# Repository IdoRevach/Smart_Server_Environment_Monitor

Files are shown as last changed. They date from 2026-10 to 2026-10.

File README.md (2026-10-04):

# Smart Server Environment Monitor

I leave a local server running my backend projects 24/7, and I want a physical dashboard to monitor its physical environment. 

I'll use a Raspberry Pi 4, a DHT22 sensor, and some LEDs inside a custom case. The Pi will run a web server so I can check the stats, and the LEDs will alert me if the area around the hardware gets too warm.

## System Architecture

The system reads temperature and humidity data from the DHT22 sensor, processes it on the Raspberry Pi 4, and triggers the warning LEDs if thresholds are exceeded. Below is the initial design concept:

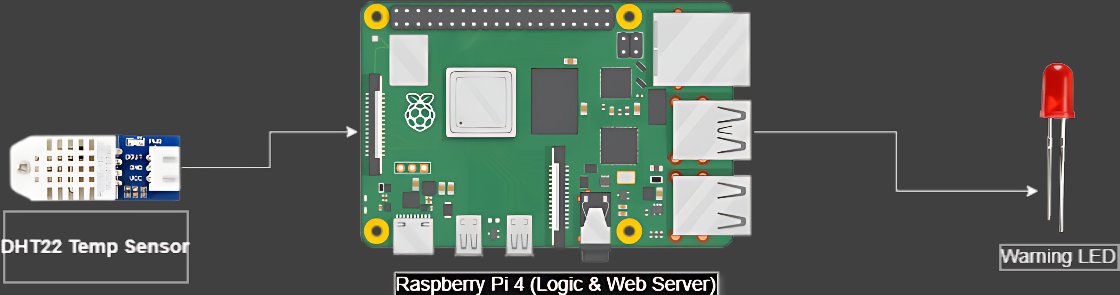
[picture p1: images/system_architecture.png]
System Architecture


## Why a Raspberry Pi 4?

I know an ESP32 or Arduino could just read a sensor and turn on a light. The problem is that reading the live temperature is not enough here. I want to save the data history to see if the server area is getting hotter over time.

That is why I am going with the Pi 4. It works like an actual server. I can run Node.js and a SQLite database right on the board to keep months of records. Small microcontrollers do not handle databases and web dashboards very well. Also, having a real Linux system means I can easily add Discord or WhatsApp alerts later without dealing with annoying C++ network code.

## Hardware List

The core components for this build are:

* Raspberry Pi 4 Model B
* DHT22 Temperature and Humidity Sensor
* Red Warning LED
* Basic wiring parts (jumper wires and a resistor)

### Wiring Schematic

The schematic below outlines the GPIO connections for the components. The DHT22 requires 3.3V power, and the status LED is connected with a 330Ω resistor to prevent overdrawing current from the Pi.

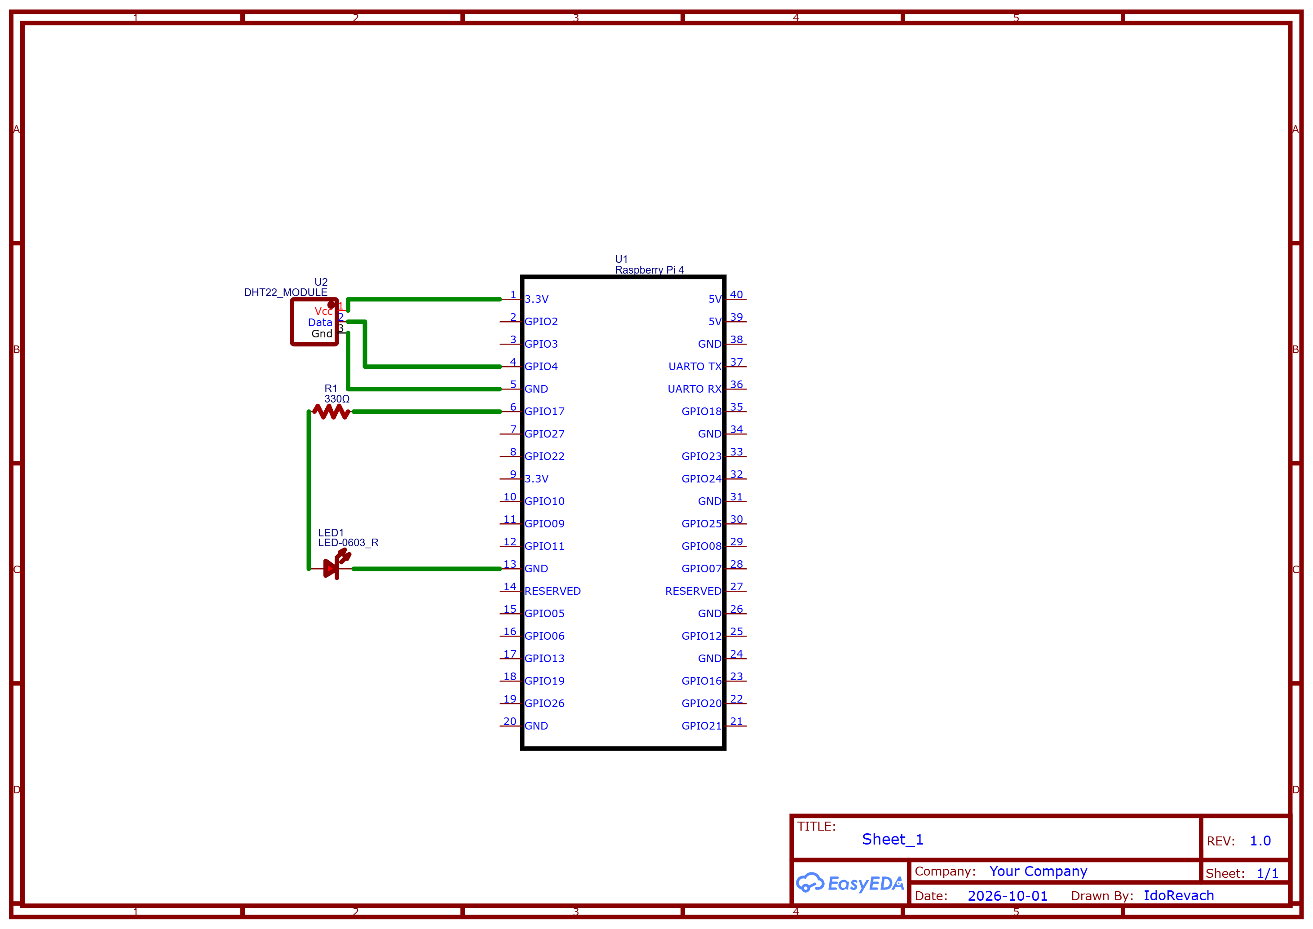
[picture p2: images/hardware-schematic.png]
hardware-schematic


### Software Stack

The backend is written in Node.js, running as a background service on the Pi. I wanted a lightweight stack that can poll the sensor, log the data, and serve a simple dashboard without eating up system resources.

*   **Node.js Server:** Handles the main polling loop for the DHT22 and runs the API endpoints.
*   **SQLite:** Used for local data logging. It's perfectly suited for this because it stores everything in a single local file, avoiding the overhead of a full database server while still letting me query historical temperature trends.
*   **GPIO Control:** The backend parses the sensor data and pulls GPIO17 HIGH to trigger the warning LED if the temperature crosses a defined threshold.
*   **Frontend Dashboard:** A basic HTML/JS page that fetches the latest stats from the Node API to display current temperature, humidity, and the LED warning status.

## Enclosure & 3D Design

I'm currently applying for a hardware grant through Hack Club's Half Life program, so I don't have the Raspberry Pi 4 or the sensors yet. To make sure the project is ready when the parts arrive, I designed a custom enclosure in Onshape.

Leaving a bare board and breadboard sitting on my server isn't ideal. Also, since Pi 4s are known to run hot, I had to make sure the board's heat wouldn't affect the DHT22 readings. The case design includes ventilation slots to isolate the sensor and allow for proper airflow.

The 3D renders and STL files are available below:

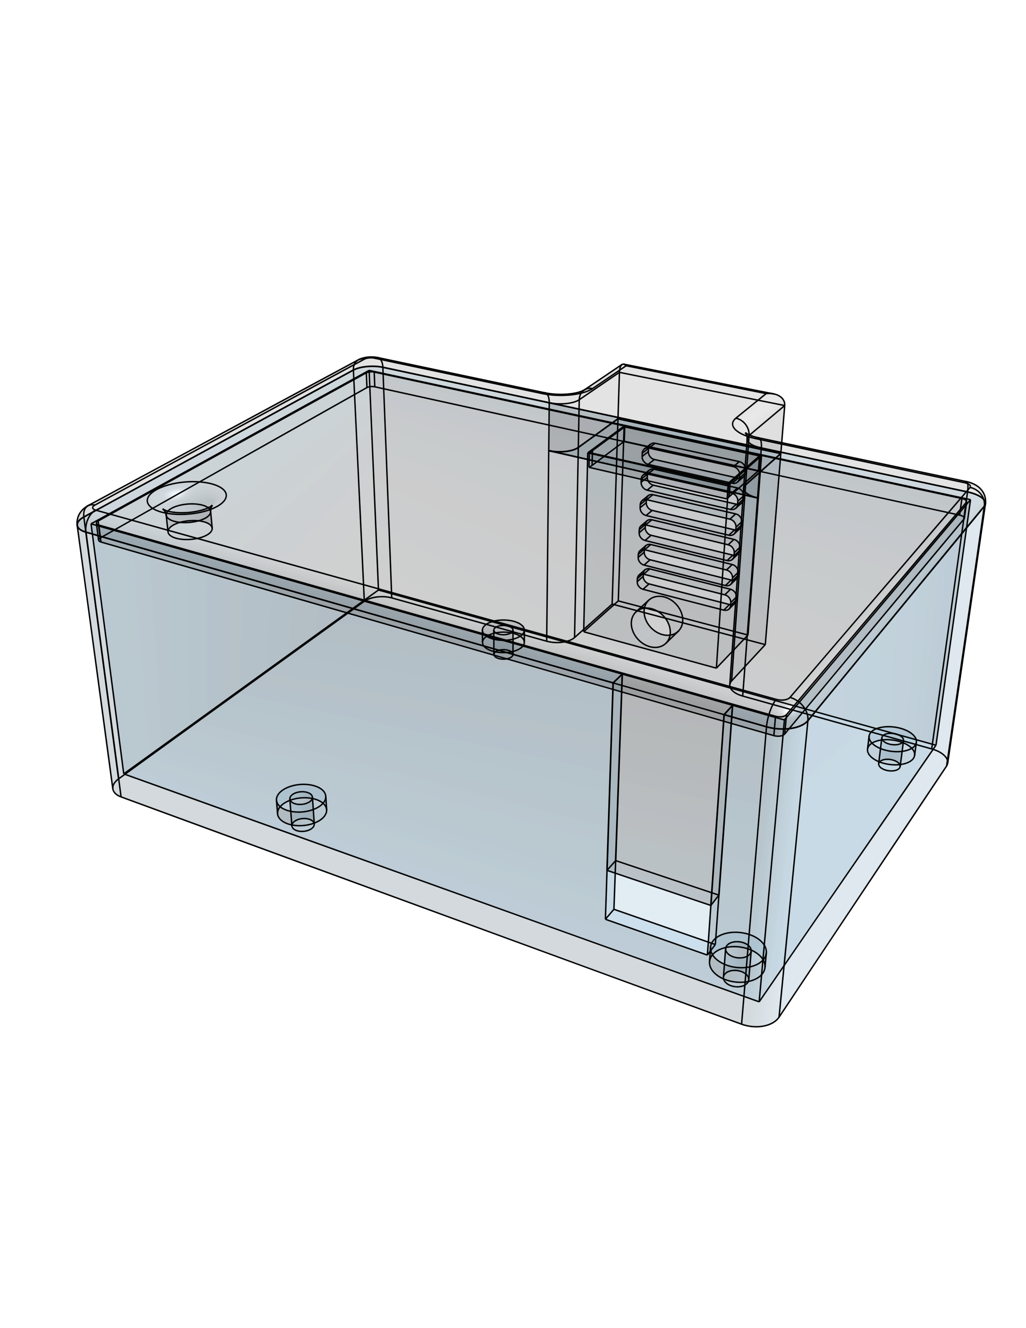
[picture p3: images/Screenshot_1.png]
Enclosure Internals

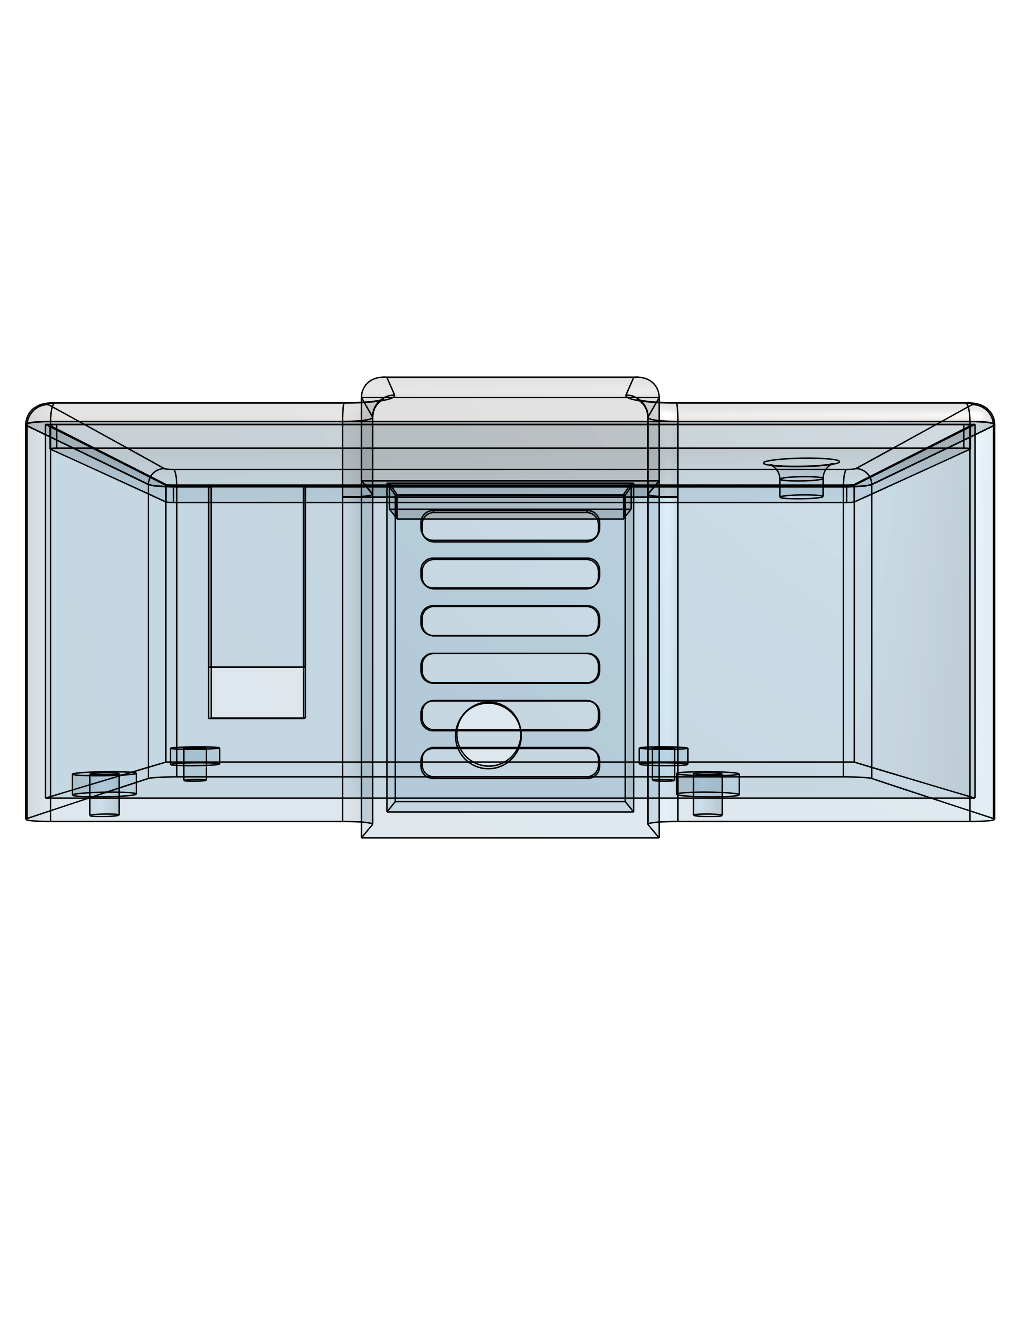
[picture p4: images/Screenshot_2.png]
Enclosure Top View

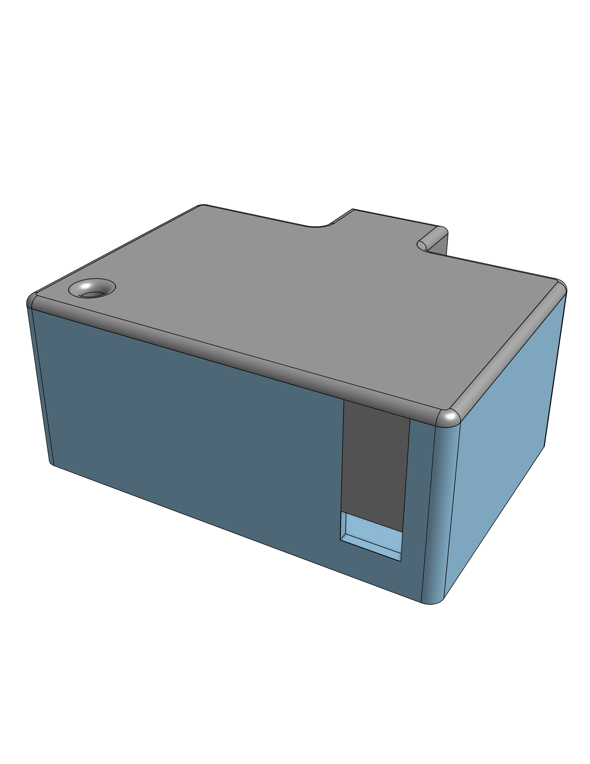
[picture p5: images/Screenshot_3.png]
Enclosure Side View

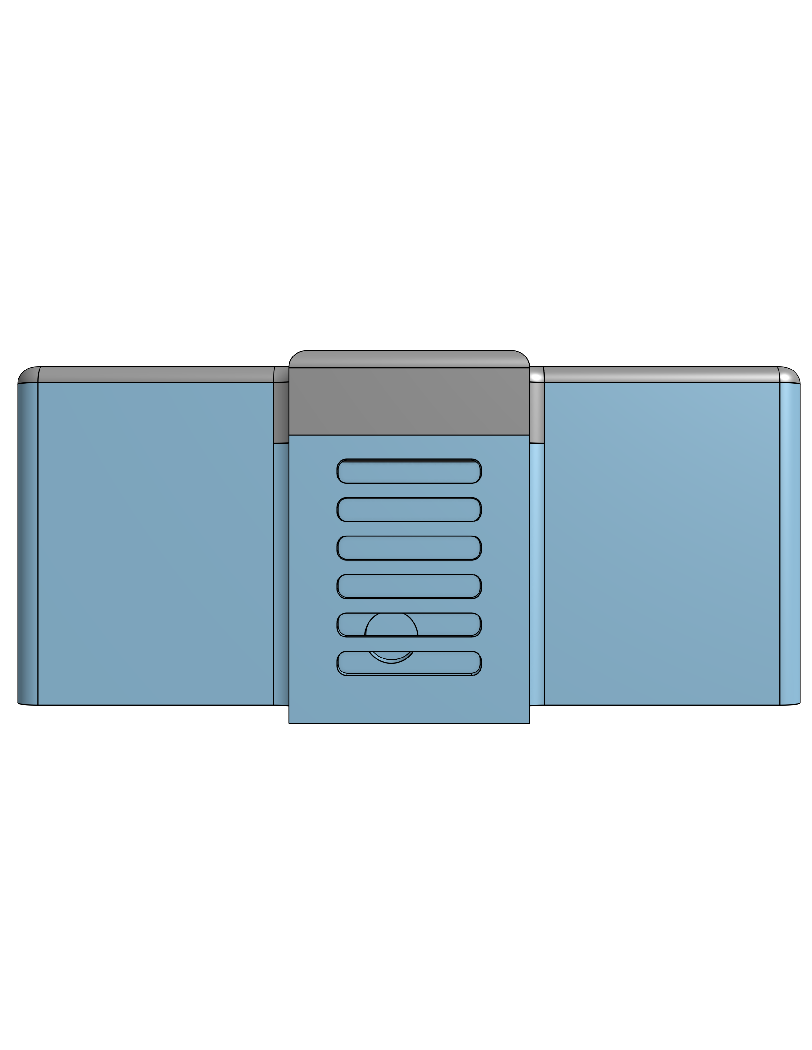
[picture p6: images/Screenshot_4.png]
Enclosure Front View


* [Base STL Model](stl/SentinelNode_RPi4_Base_v1.stl)
* [Lid STL Model](stl/SentinelNode_RPi4_Lid_v1.stl)

### Reality Check and Design Pivot
When I started putting together the final parts list I hit a wall with the Tier 2 funding limit. A Raspberry Pi 4 costs way more than the 65 dollars allowed. I looked into moving up to Tier 3, but that requires adding a motorized component to the build. Adding a fan or a servo just to inflate the budget felt like over engineering a project that should remain simple and reliable.

This forced me to look back at my original reason for using a Pi 4. I wanted to avoid writing annoying network code in C++ and I wanted a real database to keep history. Then I realized that the physical monitor is literally sitting right next to my 24/7 backend server. There is no reason the monitor itself needs to host the database.

I am swapping the Pi 4 for a cheap ESP32 C6 development board. The ESP32 will act as a dumb sensor node. All it has to do is read the DHT22 and send a basic HTTP POST request over the local Wi-Fi to my main server. My actual server will run the Node.js API, write the history to SQLite, and host the web dashboard. This keeps the project well within the Tier 2 budget and honestly makes the whole architecture much smarter by offloading the heavy work to the machine that is actually built for it.

### V2 Architecture: The Distributed Approach

With the pivot to the ESP32-C6, the system architecture is now distributed. The ESP32 acts purely as an edge sensor node, while my existing 24/7 server handles the backend logic, database, and dashboard.

**1. The Edge Node (ESP32-C6):**
The microcontroller's only job is to poll the DHT22 sensor for temperature and humidity data and send it as a JSON payload via HTTP POST requests over the local Wi-Fi. It also controls the red warning LED, toggling it based on predefined temperature thresholds to provide immediate physical feedback.

**2. The Backend (Existing Local Server):**
Instead of running on the monitor itself, the Node.js API and SQLite database now live on my main server. The backend receives the incoming POST requests, securely logs the timeseries data into the SQLite database, and serves the frontend web dashboard. 

Here is the updated system architecture:

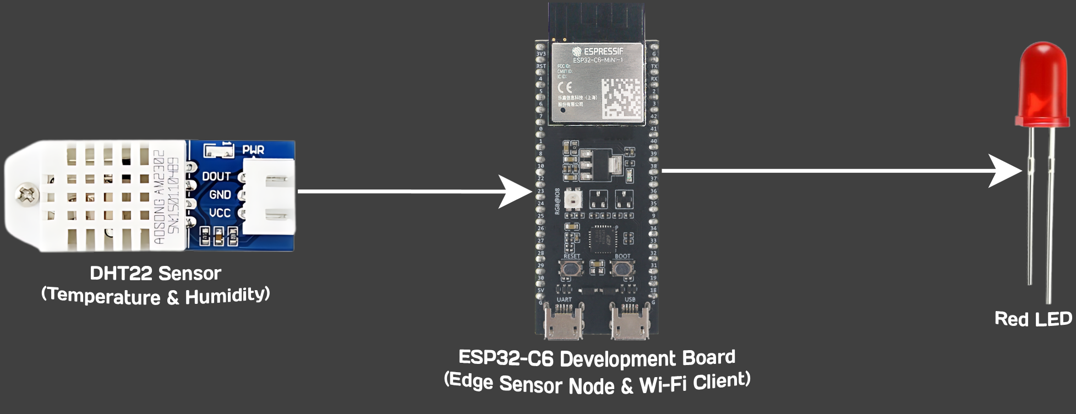
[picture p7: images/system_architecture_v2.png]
System Architecture V2


### Updated V2 Hardware Design

Below is the updated engineering schematic for the new ESP32-C6 electrical setup:

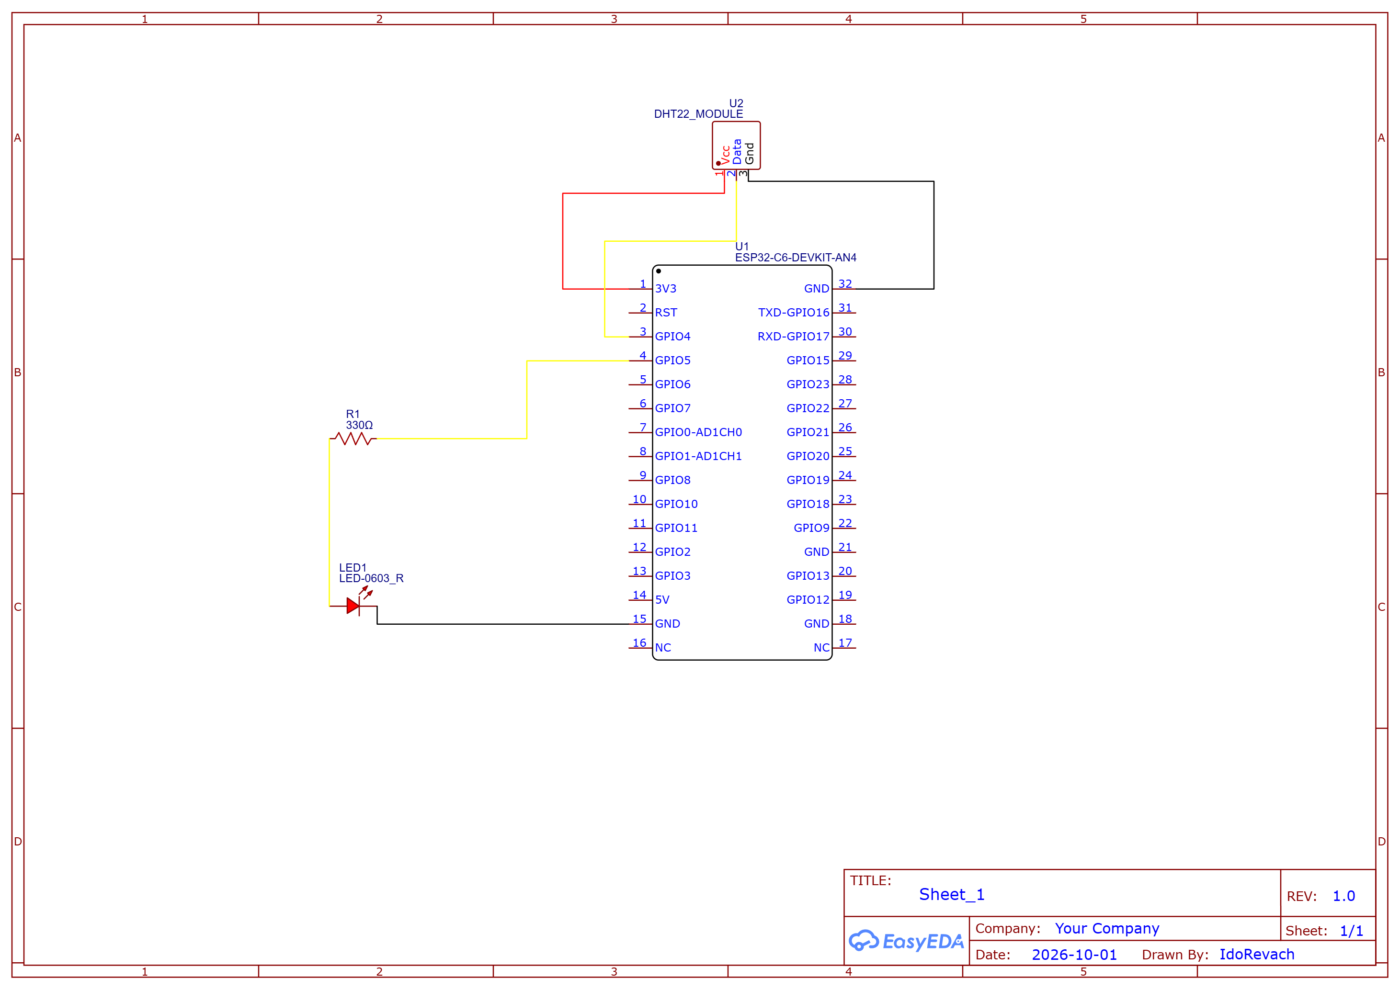
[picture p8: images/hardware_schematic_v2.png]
Electrical Schematic V2


## 3D Enclosure
I had to update the Onshape model to fit the ESP32 footprint instead of the Pi. The case separates the sensor from the board's heat.

The 3D renders and STL files are available below:

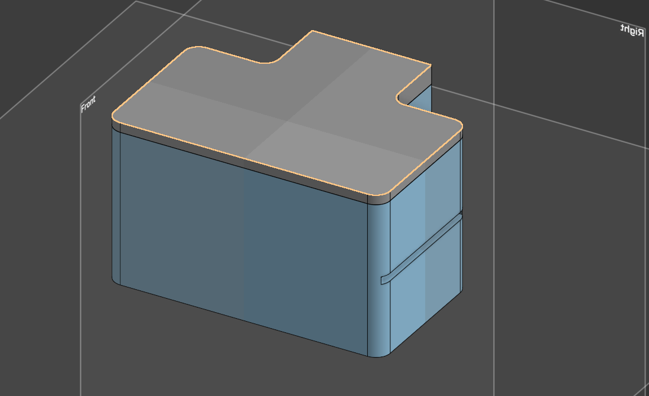
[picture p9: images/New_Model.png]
Case Front

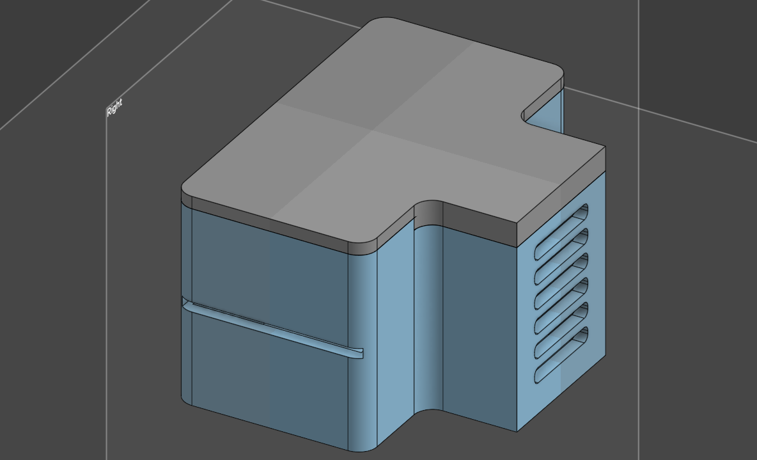
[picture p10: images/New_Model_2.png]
Case Side

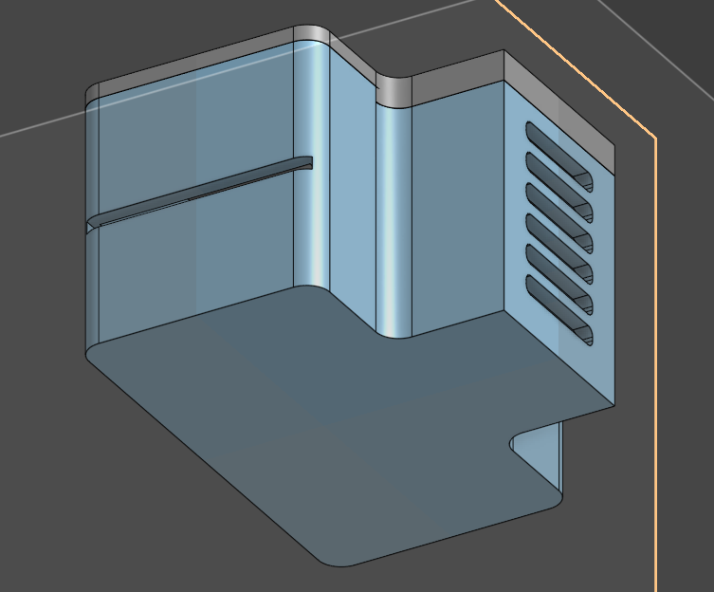
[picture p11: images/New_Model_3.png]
Case Internals


* [Base STL Model](stl/SentinelNode_ESP32_Base_v2.stl)
* [Lid STL Model](stl/SentinelNode_ESP32_Lid_v2.stl)

## Code & Setup
I uploaded everything straight to the root directory for now. (Note: I accidentally named them `main.py.py` and `server.js.js` on upload, just rename them back to normal when you clone).

* **ESP32:** Flash it with MicroPython, update the Wi-Fi details, and run `main.py`.
* **Backend:** Run `npm install express better-sqlite3`. 
* **Dashboard:** Make a folder called `public` next to the server script and put `index.html` inside it. 
* Run `node server.js` and hit port 3000 in your browser.

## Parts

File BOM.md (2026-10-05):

# Smart Server Environment Monitor — bill of materials

<!-- Generated by Half Life from project cmuoqo1p400re01s1fbd7emb1. Edits here are overwritten on the next sync. -->
<!-- Generated: 2026-10-05T03:29:06.988Z -->

> [!NOTE]
> This parts list is mirrored from [Half Life](https://halflife.hackclub.com). Editing it here will not change the platform's copy, and the next sync overwrites this file.

| Week | Tier | Parts funding |
| --- | --- | --- |
| Warm-up | Tier 2 | $65.00 |

| Part | What it's for | Qty | Unit | Total | Vendor |
| --- | --- | --- | --- | --- | --- |
| [ESP32-C6-N16 development board (pin soldered)](https://piitel.co.il/shop/esp32-c6-n16-development-board-pin-soldered/) | Main controller (reads sensor and handles Wi-Fi POST requests) | 1 | $16.18 | $16.18 | [Piltel](https://piitel.co.il/shop/esp32-c6-n16-development-board-pin-soldered/) |
| [DHT22/AM2302 Temperature & Humidity Sensor](https://www.4project.co.il/product/grove-temperature-humidity-sensor-pro-am2302-dht22) | Reads the physical environment data | 1 | $15.92 | $15.92 | [4Project](https://www.4project.co.il/product/grove-temperature-humidity-sensor-pro-am2302-dht22) |
| [Red LED 10mm](https://www.4project.co.il/product/basic-led-10mm-red) | Warning indicator | 1 | $0.61 | $0.61 | [4Project](https://www.4project.co.il/product/basic-led-10mm-red) |
| [330 Ohm Resistors 1/4W (Pack of 10)](https://www.4project.co.il/product/resistor-330-kilo-ohm-0.25w-pth) | Current limiting to protect the LED | 1 | $0.97 | $0.97 | [4Project](https://www.4project.co.il/product/resistor-330-kilo-ohm-0.25w-pth) |
| [Female to Female Jumper Wires 20cm (40 pcs)](https://www.4project.co.il/product/dupont-cable-40p-20cm-female-female) | Wiring the DHT22 and LED to the ESP32 pins | 1 | $1.91 | $1.91 | [4Project](https://www.4project.co.il/product/dupont-cable-40p-20cm-female-female) |
| **Parts subtotal** | — | — | — | **$35.59** | — |
| **Tax & shipping** | — | — | — | **$14.40** | — |
| **Total** | — | — | — | **$49.99** | — |

$15.01 left of the tier's funding.

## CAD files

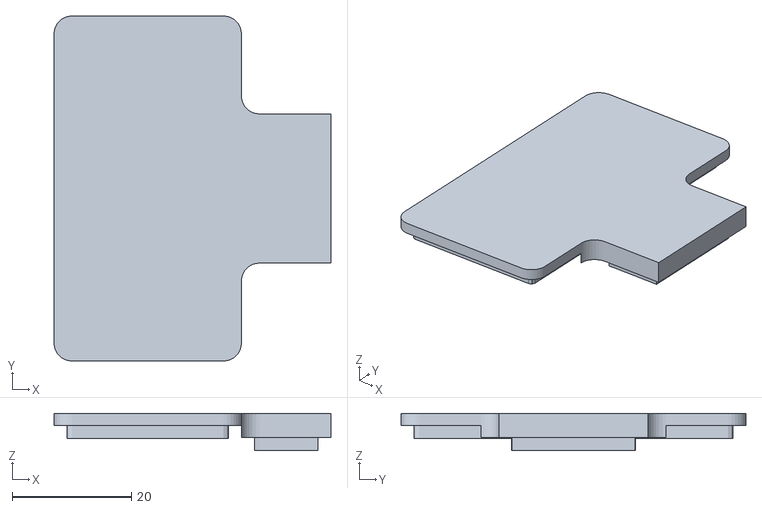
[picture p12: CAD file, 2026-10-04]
stl/SentinelNode_ESP32_Lid_v2.stl
46.4 x 57.8 x 6.20

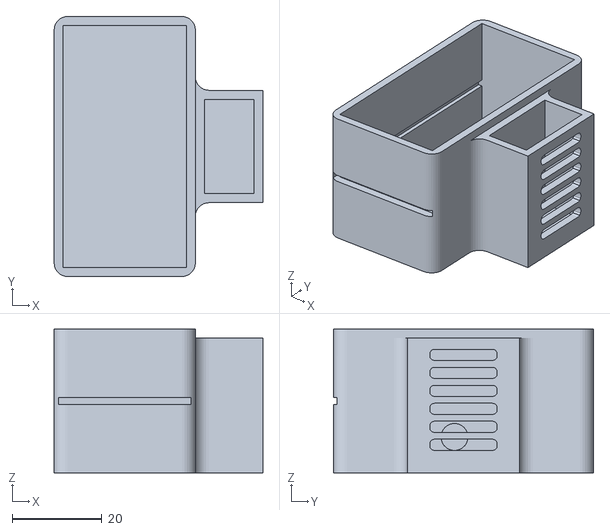
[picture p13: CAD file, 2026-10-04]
stl/SentinelNode_ESP32_Base_v2.stl
46.4 x 57.8 x 32.0

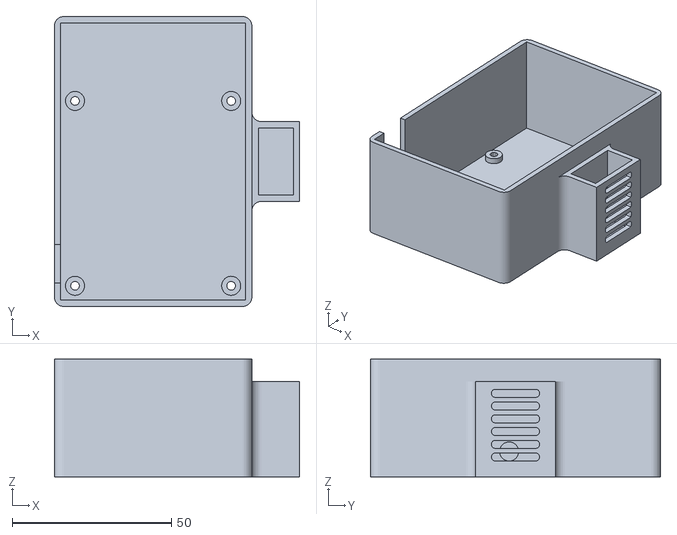
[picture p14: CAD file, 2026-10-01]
stl/SentinelNode_RPi4_Base_v1.stl
77.0 x 91.0 x 37.0

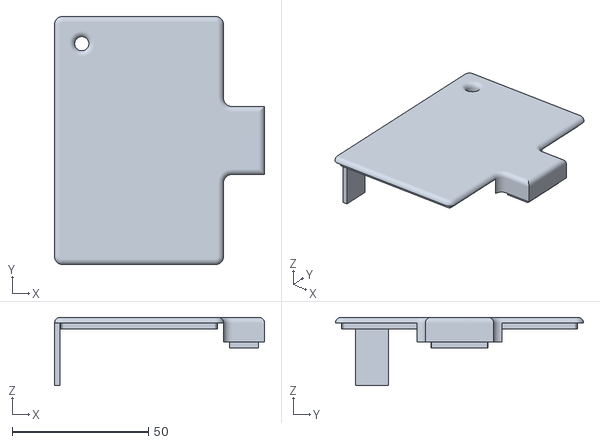
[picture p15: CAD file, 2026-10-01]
stl/SentinelNode_RPi4_Lid_v1.stl
77.0 x 91.0 x 25.0

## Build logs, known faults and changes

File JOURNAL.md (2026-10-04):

# Smart Server Environment Monitor — devlog

<!-- Generated by Half Life from project cmuoqo1p400re01s1fbd7emb1. Edits here are overwritten on the next sync. -->
<!-- Generated: 2026-10-04T20:59:15.338Z -->

> [!NOTE]
> This devlog is mirrored from [Half Life](https://halflife.hackclub.com). Editing it here will not change the platform's copy, and the next sync overwrites this file.

> I leave a local server running my backend projects 24/7, and I want a physical dashboard to monitor its physical environment. I'll use a Raspberry Pi 4, a DHT22 sensor, and some LEDs inside a custom case. The Pi will run a web server so I can check the stats, and the LEDs will alert me if the area around the hardware gets too warm.

| Week | Tier | Hours logged | Entries |
| --- | --- | --- | --- |
| Warm-up | Tier 2 | 17h | 4 |

## Contents

1. [2026-10-01 — Spent this session researching the components, planning the stack, and getting the 3D design done.](#2026-10-01-spent-this-session-researching-the-components-pla)
2. [2026-10-01 — Spent this session finalizing the Bill of Materials (BOM) and doing a reality check on local hardware prices. It turns out the Raspberry Pi 4 is way too expensive locally and blows right past the $65](#2026-10-01-spent-this-session-finalizing-the-bill-of-materia)
3. [2026-10-02 — Spent this session updating the docs and diagrams for the new V2 architecture. Since I swapped the Pi for an ESP32-C6, the old schematics were totally useless.](#2026-10-02-spent-this-session-updating-the-docs-and-diagrams)
4. [2026-10-04 — Spent this session doing some final research for the project pivot. I drew up the new hardware schematics and wrote all the code for both the server and the sensor node. To finish things off I updated](#2026-10-04-spent-this-session-doing-some-final-research-for-)

## Design

### 2026-10-01 — Spent this session researching the components, planning the stack, and getting the 3D design done.

**6.5h**

Spent this session researching the components, planning the stack, and getting the 3D design done.

I started with some research into the hardware requirements to pick the right parts for the job. Instead of a basic microcontroller, I went with a Raspberry Pi 4 so I can run Node.js









hardware-schematic

 and a local SQLite database to log temperature trends over time. I mapped out the wiring for the DHT22 sensor and warning LED (including the 330Ω resistor), planned the architecture, and wrote the documentation in the README.

After that, I modeled the custom enclosure in Onshape. Knowing the Pi 4 runs warm, I designed ventilation slots and isolated the DHT22 mount so the board heat will not mess with ambient readings. Finally, I exported the STLs, organized the repository into clean /images and /stl folders, and synced everything up.

system_architecture 1



### 2026-10-01 — Spent this session finalizing the Bill of Materials (BOM) and doing a reality check on local hardware prices. It turns out the Raspberry Pi 4 is way too expensive locally and blows right past the $65

**1.5h**

Spent this session finalizing the Bill of Materials (BOM) and doing a reality check on local hardware prices. It turns out the Raspberry Pi 4 is way too expensive locally and blows right past the $65 Tier 2 funding limit, even before calculating shipping and taxes.

I considered pushing the project to Tier 3, but that requires integrating a motorized component. Forcing a fan or a servo into the build just to get a bigger budget felt like bad engineering and unnecessary complexity for a simple environmental monitor.

Instead of over-engineering the hardware, I decided to pivot the architecture. Since this physical monitor will sit right next to my main 24/7 backend server anyway, I don't need a full Linux board to run a local SQLite database. I'm swapping the Pi 4 out for an ESP32-C6 development board. The ESP32 will act purely as a sensor node, reading the DHT22 and sending HTTP POST requests over Wi-Fi to my existing server, which will handle the Node.js API and data logging. This keeps the project under budget and makes the overall system architecture much cleaner.

צילום מסך 2026-10-01 215020

parts_02

parts_01

parts_03

### 2026-10-02 — Spent this session updating the docs and diagrams for the new V2 architecture. Since I swapped the Pi for an ESP32-C6, the old schematics were totally useless.

**2h**

Spent this session updating the docs and diagrams for the new V2 architecture. Since I swapped the Pi for an ESP32-C6, the old schematics were totally useless.

I hopped into EasyEDA and drew up a new electrical schematic. Kept it simple: the DHT22 data line goes to GPIO4, and the warning LED (with a 330Ω resistor) is on GPIO5.

After that, I made a new visual system diagram in draw.io to show exactly how the ESP32 connects to my existing local server via HTTP POST. I updated the README on GitHub with the new diagrams and wrote a quick breakdown of the distributed setup (ESP32 reads the environment, my main server handles the Node.js API and SQLite database).

The hardware logic is fully documented now. Next step is jumping into Onshape to shrink the 3D enclosure so the ESP32 actually fits.

system_architecture_v2

hardware_schematic_v2

### 2026-10-04 — Spent this session doing some final research for the project pivot. I drew up the new hardware schematics and wrote all the code for both the server and the sensor node. To finish things off I updated

**7h**

Spent this session doing some final research for the project pivot. I drew up the new hardware schematics and wrote all the code for both the server and the sensor node. To finish things off I updated the README file with the new design details and the updated images. Everything is finally ready.

New_Model_3

New_Model

New_Model_2

code_03

code_02

code_01

code_04

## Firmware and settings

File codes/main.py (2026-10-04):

import network
import time
import machine
import dht
import urequests

ssid = "MyWiFiNetwork"
password = "MyPassword123"
server_url = "http://192.168.1.14:3000/api/telemetry"
api_key = "halflife-esp32-key"

print("Booting up ESP32 Monitor...")

# Hardware setup based on the v2 schematic
sensor = dht.DHT22(machine.Pin(4))
led = machine.Pin(5, machine.Pin.OUT)
led.value(0) # start with LED off

wlan = network.WLAN(network.STA_IF)
wlan.active(True)
wlan.connect(ssid, password)

print("Connecting to WiFi", end="")
while not wlan.isconnected():
    print(".", end="")
    time.sleep(0.5)
print("\nConnected! IP Address:", wlan.ifconfig()[0])

while True:
    try:
        # make sure we are still online
        if not wlan.isconnected():
            print("WiFi disconnected! Reconnecting...")
            wlan.connect(ssid, password)
            while not wlan.isconnected():
                time.sleep(1)
            print("Reconnected.")

        print("Reading sensor...")
        sensor.measure()
        t = sensor.temperature()
        h = sensor.humidity()
        
        print(f"Temp: {t}C, Humidity: {h}%")
        
        # trigger local warning if it gets too hot (28C is the threshold for now)
        if t > 28.0:
            print("WARNING: Temp over 28! LED ON")
            led.value(1)
            alert = 1
        else:
            led.value(0)
            alert = 0
            
        payload = {
            "temperature": t,
            "humidity": h,
            "alert_active": alert
        }
        
        headers = {"Content-Type": "application/json", "x-api-key": api_key}
        
        print(f"Sending POST to {server_url}...")
        res = urequests.post(server_url, json=payload, headers=headers)
        print("Server responded with status:", res.status_code)
        
        # MUST close this or the ESP32 will run out of memory after a few hours
        res.close()
        
    except Exception as e:
        # just log it and keep going, don't crash the loop
        print("An error occurred in the loop:", e)
        
    print("Sleeping for 15 seconds...\n---")
    time.sleep(15)

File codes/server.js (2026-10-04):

const express = require('express');
const Database = require('better-sqlite3');
const path = require('path');

const app = express();
const PORT = process.env.PORT || 3000;
const API_KEY = process.env.API_KEY || 'halflife-esp32-key';

const db = new Database('monitor.db');
db.pragma('journal_mode = WAL');

db.exec(`
  CREATE TABLE IF NOT EXISTS telemetry (
    id INTEGER PRIMARY KEY AUTOINCREMENT,
    timestamp DATETIME DEFAULT CURRENT_TIMESTAMP,
    temperature REAL NOT NULL,
    humidity REAL NOT NULL,
    alert_active INTEGER NOT NULL
  )
`);

// Prepare statements once for better performance
const insertTelemetry = db.prepare('INSERT INTO telemetry (temperature, humidity, alert_active) VALUES (?, ?, ?)');
const getCurrent = db.prepare('SELECT * FROM telemetry ORDER BY id DESC LIMIT 1');
const getHistory = db.prepare('SELECT * FROM telemetry ORDER BY id DESC LIMIT 50');

app.use(express.json());
app.use(express.static(path.join(__dirname, 'public')));

const authMiddleware = (req, res, next) => {
  const key = req.headers['x-api-key'];
  if (!key || key !== API_KEY) {
    return res.status(401).json({ error: 'Unauthorized' });
  }
  next();
};

app.post('/api/telemetry', authMiddleware, (req, res) => {
  const { temperature, humidity, alert_active } = req.body;

  if (typeof temperature !== 'number' || typeof humidity !== 'number') {
    return res.status(400).json({ error: 'Invalid payload' });
  }

  try {
    const info = insertTelemetry.run(temperature, humidity, alert_active ? 1 : 0);
    console.log(`[\({new Date().toISOString()}] Logged - Temp:\){temperature}°C, Hum: \({humidity}%, Alert:\){alert_active}`);
    res.status(201).json({ success: true, id: info.lastInsertRowid });
  } catch (err) {
    console.error('Database write error:', err);
    res.status(500).json({ error: 'Internal server error' });
  }
});

app.get('/api/current', (req, res) => {
  try {
    const data = getCurrent.get();
    res.json(data || {});
  } catch (err) {
    console.error('Database read error:', err);
    res.status(500).json({ error: 'Internal server error' });
  }
});

app.get('/api/history', (req, res) => {
  try {
    const data = getHistory.all();
    res.json(data.reverse());
  } catch (err) {
    console.error('Database read error:', err);
    res.status(500).json({ error: 'Internal server error' });
  }
});

app.listen(PORT, '0.0.0.0', () => {
  console.log(`Server listening on 0.0.0.0:${PORT}`);
});

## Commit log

2026-10-01 Add wiring schematic section to README
    Added wiring schematic and GPIO connection details for components.
2026-10-01 Update image paths and STL file links in README
2026-10-04 Enhance README with 3D model and setup instructions
    Updated README with new 3D enclosure details and code setup instructions.
2026-10-04 Rename ESP32 (1).stl to stl/ESP32 (1).stl
    [ESP32 (1).stl]
2026-10-04 Rename ESP32 (1).stl to SentinelNode_ESP32_Lid_v2.stl
    [SentinelNode_ESP32_Lid_v2.stl]
2026-10-04 Fix image paths and add STL file references
    Updated image paths and added STL file links for the 3D enclosure.
